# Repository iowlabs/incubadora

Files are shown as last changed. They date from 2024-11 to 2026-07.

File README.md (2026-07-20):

# incubadora

This project consists of a low-cost incubator for biotechnology instrumentation. Its design is easy to integrate and adaptable to different scenarios. It is ideal for remote laboratories, field deployments, school laboratories, and educational kits.

For this project, a PCB was designed that implements the electronics to control the operation of an incubator. It includes a temperature control and a *shaker* for sample agitation.

The PCB is based on a ESP32 so It can implement remote control and monitoring via Wi-Fi or BLE. It also has access to a USB communication interface for parameter configuration, curve generation, and data acquisition. It also features a simple interface that uses an LCD display and a rotary encoder as an alternative control method.

## Features.

### General features:

- Temperature Control
- Shaker RPM Control
- Simple User Interface
- WiFi Remote Control Capability
- Temperature profile programming
- easy assembly

### Hardware Features

- ESP32 Microcontroller
- PID Temperature Control Loop
	- Heater: Peltier-controlled by a H-bridge (2 separated heater channels)
	- Temperature Sensor: SHT31 ambient temperature and humidity sensor via I²C
	- Fan Assembly
- Shaker Control:
	- Nema 17 Motor
	- DRV8825 Polulu Controller
- Local User Interface
	- Rotary Encoder
	- LCD Display
	- SD Card
- WiFi Remote Control
	- MQTT Commands
- INA219 Current Sensor for Measuring Input Power Consumption

---
# Documentación

- Github repo
- Web

## Licencias

| | Licence |
|---- | --- |
|Hardware | --------- |
|Firmware and Software | --------- |
|Documentation and files | --------- |

---

# Diseño e implementación

---

## PCB
### Schematic

### pcb BOM

---

## Case 3D and structure

---

## List of components

### Assembly steps

---

## Firmware

### Used libraries

### Structure of the code

### Available Features.

---

# Application examples

## Using a portable cooler as incubator.

## Using a large incubator.

## Code to acquire and plot data in real time.

## Controlling via MQTT.

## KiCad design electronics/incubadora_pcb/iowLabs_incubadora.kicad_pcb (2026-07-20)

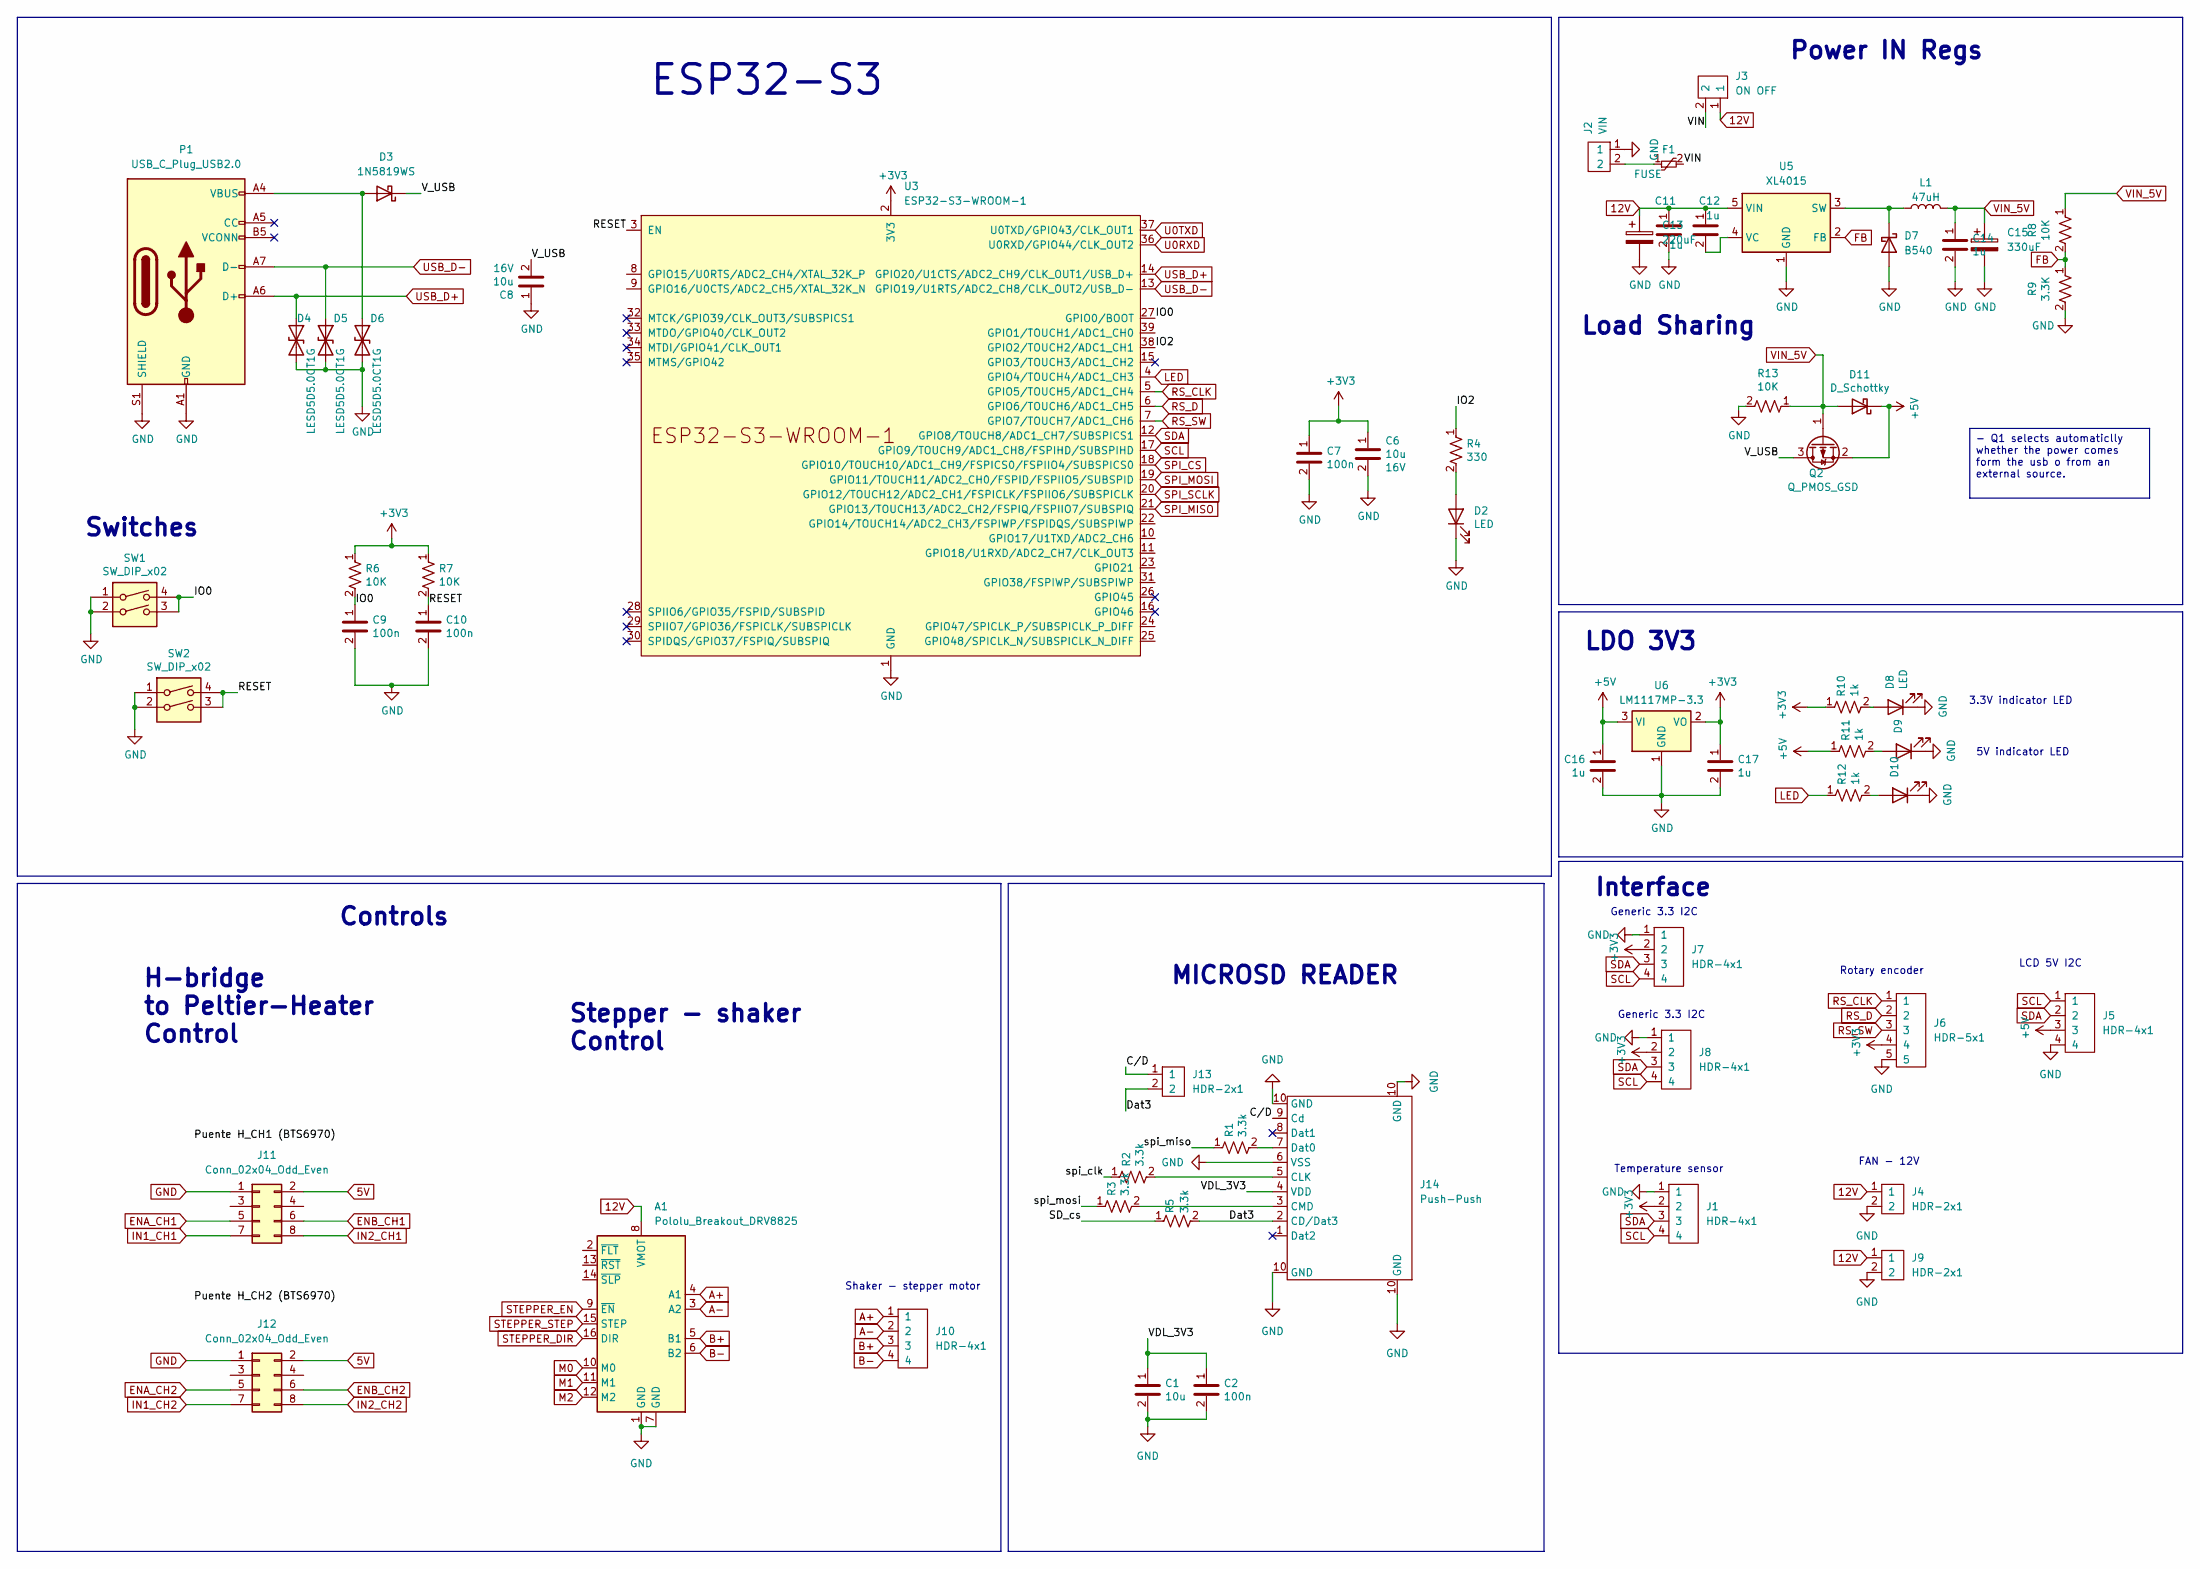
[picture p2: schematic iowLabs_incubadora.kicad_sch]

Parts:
A1: Pololu_Breakout_DRV8825; Pololu_Breakout-16_15.2x20.3mm
C1, C6, C8: 10u; C_0805_2012Metric; Voltage rated 16V
C2, C7, C9, C10: 100n; C_0603_1608Metric; Voltage rated 16V
C11, C12, C14, C16, C17: 1u; C_0805_2012Metric; Voltage rated 16V
C13: 220uF; CP_Elec_8x10.5; Voltage 50V
C15: 330uF; CP_Elec_8x10.5; Voltage 25V
D2, D8, D9, D10: LED; LED_0603_1608Metric
D3: 1N5819WS; D_SOD-323
D4, D5, D6: LESD5D5.0CT1G; D_SOD-523
D7: B540; D_SMB_Handsoldering
D11: D_Schottky; D_SMA
F1: FUSE; Fuse_1206_3216Metric
J1, J5, J7, J8, J10: HDR-4x1; JST_XH_B4B-XH-A_1x04_P2.50mm_Vertical
J2: VIN; Tb-2x1-5p-TH-V
J3: ON OFF; PinHeader_1x02_P2.54mm_Vertical
J4, J9: HDR-2x1
J6: HDR-5x1; JST_XH_B5B-XH-A_1x05_P2.50mm_Vertical
J11, J12: Conn_02x04_Odd_Even; PinHeader_2x04_P2.54mm_Vertical
J13: HDR-2x1; PinHeader_1x02_P2.54mm_Vertical
J14: microSD_push_push
L1: 47uH; L_12x12mm_H8mm
P1: USB_C_Plug_USB2.0; USB_C_Receptacle_GCT_USB4105-xx-A_16P_TopMnt_Horizontal
Q2: Q_PMOS_GSD; SOT-23
R1, R2, R3, R5: 3.3k; R_0603_1608Metric
R4: 330; R_0603_1608Metric
R6, R7, R8, R13: 10K; R_0603_1608Metric
R9: 3.3K; R_0603_1608Metric
R10, R11, R12: 1k; R_0603_1608Metric
SW1, SW2: SW_DIP_x02; SMD_SWITCH
U3: ESP32-S3-WROOM-1
U5: XL4015; TO-263-5_TabPin3
U6: LM1117MP-3.3; SOT-223-3_TabPin2

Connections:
5V: J11.2, J12.2
12V: A1.8 (VMOT), C11.1, C12.1, C13.1, J3.1, J4.1, J9.1, U5.5 (VIN)
+3V3: C6.1, C7.1, C17.1, J1.2, J6.4, J7.2, J8.2, R6.1, R7.1, R10.1, U3.2 (3V3), U6.2 (VO)
+5V: C16.1, D11.1 (K), J5.3, Q2.2 (S), R11.1, U6.3 (VI)
/C/D: J13.1, J14.9 (Cd)
/Dat3: J13.2, J14.2 (CD/Dat3), R5.2
/IO0: C9.1, R6.2, SW1.3, SW1.4, U3.27 (GPIO0/BOOT)
/IO2: R4.1, U3.38 (GPIO2/TOUCH2/ADC1_CH1)
/RESET: C10.1, R7.2, SW2.3, SW2.4, U3.3 (EN)
/SD_cs: R5.1
/VDL_3V3: C1.1, C2.1, J14.4 (VDD)
/VIN: F1.2, J3.2
/V_USB: C8.2, D3.1 (K), Q2.3 (D)
/spi_clk: R2.1
/spi_miso: R1.1
/spi_mosi: R3.1
A+: A1.4 (A1), J10.1
A-: A1.3 (A2), J10.2
B+: A1.5 (B1), J10.3
B-: A1.6 (B2), J10.4
ENA_CH1: J11.5
ENA_CH2: J12.5
ENB_CH1: J11.6
ENB_CH2: J12.6
FB: R8.2, R9.1, U5.2 (FB)
GND: A1.1 (GND), A1.7 (GND), C1.2, C2.2, C6.2, C7.2, C8.1, C9.2, C10.2, C11.2, C13.2, C14.2, C15.2, C16.2, C17.2, D2.1 (K), D4.2 (A2), D5.2 (A2), D6.2 (A2), D7.2 (A), D8.1 (K), D9.1 (K), D10.1 (K), J1.1, J2.1, J4.2, J5.4, J6.5, J7.1, J8.1, J9.2, J11.1, J12.1, J14.6 (VSS), J14.10 (GND), P1.A1 (GND), P1.A12 (GND), P1.B1 (GND), P1.B12 (GND), P1.S1 (SHIELD), R9.2, R13.2, SW1.1, SW1.2, SW2.1, SW2.2, U3.1 (GND), U3.40 (GND), U3.41 (GND), U5.1 (GND), U6.1 (GND)
IN1_CH1: J11.7
IN1_CH2: J12.7
IN2_CH1: J11.8
IN2_CH2: J12.8
LED: R12.1, U3.4 (GPIO4/TOUCH4/ADC1_CH3)
M0: A1.10 (M0)
M1: A1.11 (M1)
M2: A1.12 (M2)
unnamed: D2.2 (A), R4.2
unnamed: D3.2 (A), D6.1 (A1), P1.A4 (VBUS), P1.A9 (VBUS), P1.B4 (VBUS), P1.B9 (VBUS)
unnamed: D7.1 (K), L1.1, U5.3 (SW)
unnamed: D8.2 (A), R10.2
unnamed: D9.2 (A), R11.2
unnamed: D10.2 (A), R12.2
unnamed: F1.1, J2.2
unnamed: J14.5 (CLK), R2.2
unnamed: J14.3 (CMD), R3.2
unnamed: J14.7 (Dat0), R1.2
unnamed: C12.2, U5.4 (VC)
RS_CLK: J6.1, U3.5 (GPIO5/TOUCH5/ADC1_CH4)
RS_D: J6.2, U3.6 (GPIO6/TOUCH6/ADC1_CH5)
RS_SW: J6.3, U3.7 (GPIO7/TOUCH7/ADC1_CH6)
SCL: J1.4, J5.1, J7.4, J8.4, U3.17 (GPIO9/TOUCH9/ADC1_CH8/FSPIHD/SUBSPIHD)
SDA: J1.3, J5.2, J7.3, J8.3, U3.12 (GPIO8/TOUCH8/ADC1_CH7/SUBSPICS1)
SPI_CS: U3.18 (GPIO10/TOUCH10/ADC1_CH9/FSPICS0/FSPIIO4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)
SPI_MISO: U3.21 (GPIO13/TOUCH13/ADC2_CH2/FSPIQ/FSPIIO7/S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)
SPI_MOSI: U3.19 (GPIO11/TOUCH11/ADC2_CH0/FSPID/FSPIIO5/S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)
SPI_SCLK: U3.20 (GPIO12/TOUCH12/ADC2_CH1/FSPICLK/FSPIIO6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)
STEPPER_DIR: A1.16 (DIR)
STEPPER_EN: A1.9 (~EN)
STEPPER_STEP: A1.15 (STEP)
U0RXD: U3.36 (U0RXD/GPIO44/CLK_OUT2)
U0TXD: U3.37 (U0TXD/GPIO43/CLK_OUT1)
USB_D+: D4.1 (A1), P1.A6 (D+), U3.14 (GPIO20/U1CTS/ADC2_CH9/CLK_OUT1/USB_D+)
USB_D-: D5.1 (A1), P1.A7 (D-), U3.13 (GPIO19/U1RTS/ADC2_CH8/CLK_OUT2/USB_D-)
VIN_5V: C14.1, C15.1, D11.2 (A), L1.2, Q2.1 (G), R8.1, R13.1

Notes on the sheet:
LCD 5V I2C
3.3V indicator LED
H-bridge to Peltier-Heater Control
MICROSD READER
Power IN Regs
Load Sharing
5V indicator LED
Interface
FAN - 12V
Shaker - stepper motor
Controls
Generic 3.3 I2C
Stepper - shaker Control
Switches
ESP32-S3
Rotary encoder
LDO 3V3
Temperature sensor
- Q1 selects automaticlly whether the power comes form the usb o from an external source.

Board: 2 copper layers, 59 parts (0 on the bottom side), 38 nets, no tracks yet.

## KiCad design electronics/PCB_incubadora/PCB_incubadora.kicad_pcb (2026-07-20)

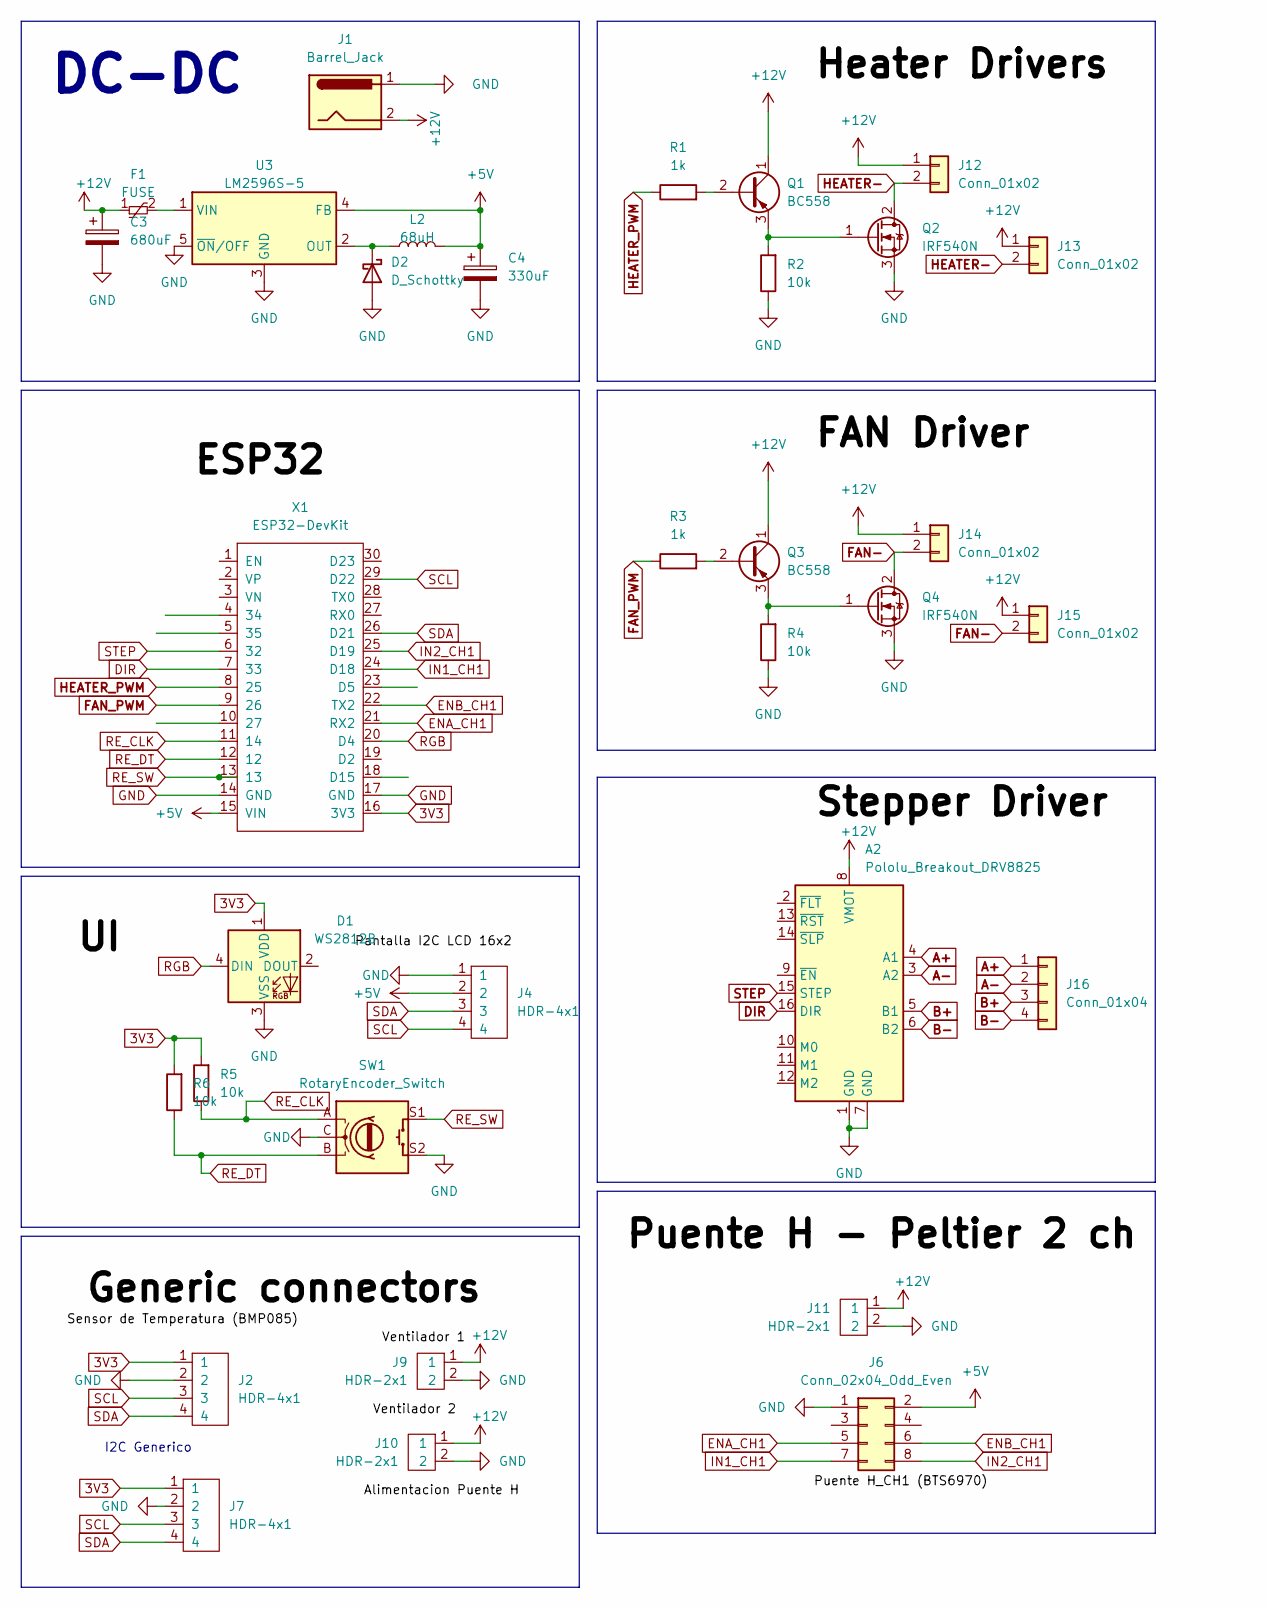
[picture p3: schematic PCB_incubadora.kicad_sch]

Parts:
A2: Pololu_Breakout_DRV8825; Pololu_Breakout-16_15.2x20.3mm
C3: 680uF; CP_Elec_10x10
C4: 330uF; CP_Elec_10x10
D1: WS2812B; LED_WS2812B_PLCC4_5.0x5.0mm_P3.2mm
D2: D_Schottky; D_SMB_Handsoldering
F1: FUSE; Fuse_1206_3216Metric
J1: Barrel_Jack; BarrelJack_Horizontal
J2, J7: HDR-4x1; JST_XH_B4B-XH-A_1x04_P2.50mm_Vertical
J4: HDR-4x1; OLED 0'96 SPI module
J6: Conn_02x04_Odd_Even; PinHeader_2x04_P2.54mm_Vertical
J9, J10, J11: HDR-2x1; TerminalBlock_4Ucon_1x02_P3.50mm_Horizontal
J12, J13, J14, J15: Conn_01x02; TerminalBlock_4Ucon_1x02_P3.50mm_Horizontal
J16: Conn_01x04; TerminalBlock_4Ucon_1x04_P3.50mm_Horizontal
L2: 68uH; L_12x12mm_H6mm
Q1, Q3: BC558; TO-92_Inline
Q2, Q4: IRF540N; TO-220-3_Vertical
R1, R3: 1k; R_0603_1608Metric
R2, R4, R5, R6: 10k; R_0603_1608Metric
SW1: RotaryEncoder_Switch; RotaryEncoder_Alps_EC11E-Switch_Vertical_H20mm
U3: LM2596S-5; TO-263-5_TabPin3
X1: ESP32-DevKit; ESP32_devkit

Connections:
3V3: D1.1 (VDD), J2.1, J7.1, R5.2, R6.2, X1.16 (3V3)
+5V: C4.1, J4.2, J6.2, L2.2, U3.4 (FB), X1.15 (VIN)
+12V: A2.8 (VMOT), C3.1, F1.1, J1.2, J9.1, J10.1, J11.1, J12.1, J13.1, J14.1, J15.1, Q1.1 (C), Q3.1 (C)
A+: A2.4 (A1), J16.1
A-: A2.3 (A2), J16.2
B+: A2.5 (B1), J16.3
B-: A2.6 (B2), J16.4
DIR: A2.16 (DIR), X1.7 (33)
ENA_CH1: J6.5, X1.21 (RX2)
ENB_CH1: J6.6, X1.22 (TX2)
FAN-: J14.2, J15.2, Q4.2 (D)
FAN_PWM: R3.1, X1.9 (26)
GND: A2.1 (GND), A2.7 (GND), C3.2, C4.2, D1.3 (VSS), D2.2 (A), J1.1, J2.2, J4.1, J6.1, J7.2, J9.2, J10.2, J11.2, Q2.3 (S), Q4.3 (S), R2.1, R4.1, SW1.C, SW1.S2, U3.3 (GND), U3.5 (~ON/OFF), X1.14 (GND), X1.17 (GND)
HEATER-: J12.2, J13.2, Q2.2 (D)
HEATER_PWM: R1.1, X1.8 (25)
IN1_CH1: J6.7, X1.24 (D18)
IN2_CH1: J6.8, X1.25 (D19)
unnamed: D2.1 (K), L2.1, U3.2 (OUT)
unnamed: Q1.2 (B), R1.2
unnamed: Q1.3 (E), Q2.1 (G), R2.2
unnamed: Q3.2 (B), R3.2
unnamed: Q3.3 (E), Q4.1 (G), R4.2
unnamed: F1.2, U3.1 (VIN)
RE_CLK: R5.1, SW1.A, X1.11 (14)
RE_DT: R6.1, SW1.B, X1.12
RE_SW: SW1.S1, X1.13
RGB: D1.4 (DIN), X1.20 (D4)
SCL: J2.3, J4.4, J7.3, X1.29 (D22)
SDA: J2.4, J4.3, J7.4, X1.26 (D21)
STEP: A2.15 (STEP), X1.6 (32)

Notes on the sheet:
I2C Generico
DC-DC

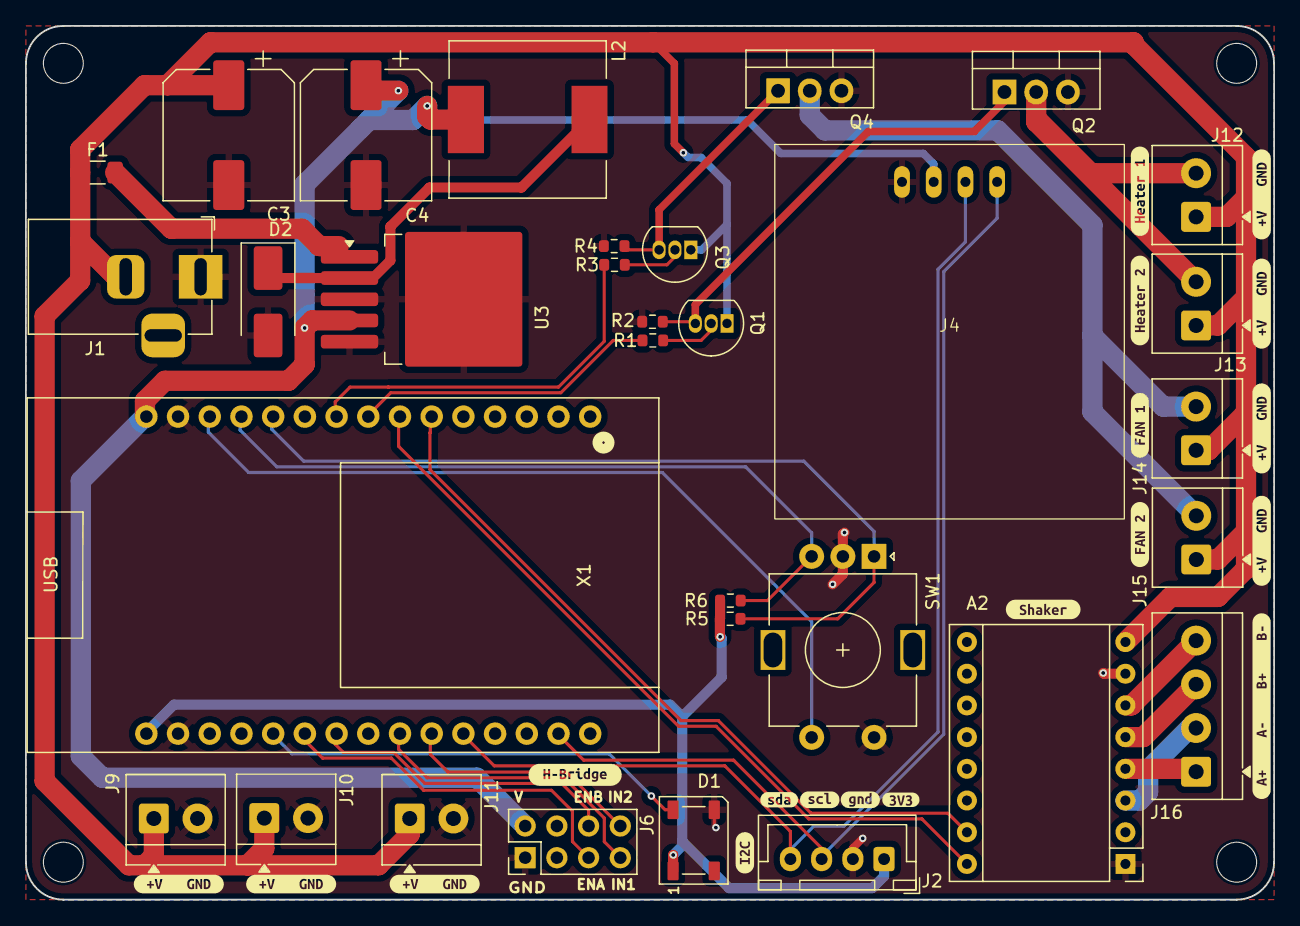
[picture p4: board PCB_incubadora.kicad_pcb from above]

Board: 2 copper layers, 100.0 x 70.0 mm, 51 parts (0 on the bottom side), 30 nets.

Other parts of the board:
kibuzzard-6A5B10A0: G***; kibuzzard-6A5B10A0
kibuzzard-6A5B10F5, kibuzzard-6A5B10F5#2, kibuzzard-6A5B10F5#3, kibuzzard-6A5B10F5#4, kibuzzard-6A5B10F5#5, kibuzzard-6A5B10F5#6, kibuzzard-6A5B10F5#7: G***; kibuzzard-6A5B10F5
kibuzzard-6A5B11C6: G***; kibuzzard-6A5B11C6
kibuzzard-6A5B13D0: G***; kibuzzard-6A5B13D0
kibuzzard-6A5B13E5: G***; kibuzzard-6A5B13E5
kibuzzard-6A5B13F6: G***; kibuzzard-6A5B13F6
kibuzzard-6A5B162D: G***; kibuzzard-6A5B162D
kibuzzard-6A5B1115: G***; kibuzzard-6A5B1115
kibuzzard-6A5B1189: G***; kibuzzard-6A5B1189
kibuzzard-6A5B1258: G***; kibuzzard-6A5B1258
kibuzzard-6A5B1282: G***; kibuzzard-6A5B1282
kibuzzard-6A5B1312: G***; kibuzzard-6A5B1312
kibuzzard-6A5B1426: G***; kibuzzard-6A5B1426

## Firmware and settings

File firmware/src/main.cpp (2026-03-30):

/*
# SPDX-FileCopyrightText: 2024 iowlabs <contacto@iowlabs.com>
#
# SPDX-License-Identifier: GPL-3.0-or-later.txt
*/

#include <Arduino.h>
#include <Wire.h>
#include <Adafruit_Sensor.h>
#include <Adafruit_SHT31.h>
#include <ArduinoJson.h>
#include <ContinuousStepper.h>
#include <LiquidCrystal_I2C.h>
#include <PID_v1.h>
#include <WiFi.h>
#include <AsyncTCP.h>
#include <ESPAsyncWebServer.h>
#include "freertos/FreeRTOS.h"
#include "freertos/task.h"
#include "freertos/semphr.h"

// Heater/H-bridge pins
#define ENA 25
#define ENB 26
#define IN1 33
#define IN2 32

// Stepper pins
#define PIN_DIR 27
#define PIN_STEP 14

// PWM channels
#define CH_H 5
#define CH_C 4

// Safe defaults and limits
constexpr float DEFAULT_TEMP_SP_C = 37.0f;
constexpr long DEFAULT_RPM = 60;
constexpr bool DEFAULT_RUN_ENABLED = false;

constexpr float TEMP_MIN_C = 15.0f;
constexpr float TEMP_MAX_C = 60.0f;
constexpr long RPM_MIN = 30;
constexpr long RPM_MAX = 90;

constexpr float STEPS_PER_REV = 1600.0f;
constexpr float RPM_TO_STEPS_PER_SEC = STEPS_PER_REV / 60.0f;

constexpr uint32_t CONTROL_INTERVAL_MS = 500;
constexpr uint32_t SSE_INTERVAL_MS = 500;

// Access point credentials (WPA2)
constexpr char AP_SSID[] = "Incubadora-ESP32";
constexpr char AP_PASSWORD[] = "incubadora32";

SemaphoreHandle_t stateMutex;

Adafruit_SHT31 sht31 = Adafruit_SHT31();
ContinuousStepper<StepperDriver> stepper;
LiquidCrystal_I2C lcd(0x27, 16, 2);

// PID setup
static double setpointPid = DEFAULT_TEMP_SP_C;
static double inputPid = 0.0;
static double outputPid = 0.0;
static double kp = 15.0;
static double ki = 2.0;
static double kd = 10.0;
PID temperaturePid(&inputPid, &outputPid, &setpointPid, kp, ki, kd, DIRECT);

// Web server + SSE
AsyncWebServer server(80);
AsyncEventSource events("/api/stream");

struct IncubatorState
{
  float temp_c;
  float temp_sp_c;
  long rpm;
  int pwm;
  bool run_enabled;
  uint32_t uptime_ms;
  char last_error[96];
};

IncubatorState gState;

const char INDEX_HTML[] PROGMEM = R"HTML(
<!doctype html>
<html lang="en">
<head>
  <meta charset="utf-8" />
  <meta name="viewport" content="width=device-width, initial-scale=1" />
  <title>Incubadora Control</title>
  <style>
    :root {
      --bg: radial-gradient(circle at 20% 20%, #14213d 0%, #0d1b2a 45%, #08121f 100%);
      --card: rgba(255, 255, 255, 0.08);
      --card-border: rgba(255, 255, 255, 0.18);
      --text: #f1f5f9;
      --muted: #cbd5e1;
      --ok: #34d399;
      --warn: #f59e0b;
      --bad: #f87171;
      --accent: #38bdf8;
      --accent-2: #22d3ee;
    }

    * { box-sizing: border-box; }

    body {
      margin: 0;
      min-height: 100vh;
      font-family: "Trebuchet MS", "Segoe UI", sans-serif;
      color: var(--text);
      background: var(--bg);
      display: grid;
      place-items: center;
      padding: 20px;
    }

    .panel {
      width: min(960px, 100%);
      border: 1px solid var(--card-border);
      background: var(--card);
      backdrop-filter: blur(8px);
      border-radius: 20px;
      padding: 20px;
      box-shadow: 0 24px 80px rgba(0, 0, 0, 0.35);
      animation: rise 450ms ease-out;
    }

    @keyframes rise {
      from { opacity: 0; transform: translateY(8px); }
      to { opacity: 1; transform: translateY(0); }
    }

    h1 {
      margin: 0 0 6px;
      font-size: clamp(1.2rem, 2.4vw, 1.8rem);
      letter-spacing: 0.04em;
      text-transform: uppercase;
    }

    .sub {
      margin: 0 0 18px;
      color: var(--muted);
      font-size: 0.95rem;
    }

    .grid {
      display: grid;
      gap: 12px;
      grid-template-columns: repeat(auto-fit, minmax(160px, 1fr));
      margin-bottom: 18px;
    }

    .card {
      background: rgba(2, 6, 23, 0.35);
      border: 1px solid rgba(148, 163, 184, 0.25);
      border-radius: 14px;
      padding: 12px;
    }

    .label {
      color: var(--muted);
      font-size: 0.78rem;
      text-transform: uppercase;
      letter-spacing: 0.08em;
    }

    .value {
      font-size: 1.4rem;
      margin-top: 4px;
      font-weight: 700;
    }

    .controls {
      display: grid;
      gap: 12px;
      grid-template-columns: repeat(auto-fit, minmax(220px, 1fr));
    }

    .input-group {
      display: grid;
      gap: 6px;
    }

    label {
      font-size: 0.85rem;
      color: var(--muted);
    }

    input {
      width: 100%;
      border-radius: 10px;
      border: 1px solid rgba(148, 163, 184, 0.4);
      background: rgba(2, 6, 23, 0.55);
      color: var(--text);
      font-size: 1rem;
      padding: 10px 12px;
      outline: none;
    }

    input:focus {
      border-color: var(--accent);
      box-shadow: 0 0 0 2px rgba(56, 189, 248, 0.25);
    }

    .actions {
      display: flex;
      gap: 8px;
      flex-wrap: wrap;
      margin-top: 2px;
    }

    button {
      border: none;
      border-radius: 10px;
      padding: 10px 14px;
      color: #042f2e;
      font-weight: 700;
      cursor: pointer;
      transition: transform 120ms ease, filter 120ms ease;
      background: linear-gradient(135deg, var(--accent), var(--accent-2));
    }

    button:hover { transform: translateY(-1px); filter: brightness(1.06); }

    .btn-stop {
      color: #450a0a;
      background: linear-gradient(135deg, #fca5a5, #f87171);
    }

    .btn-export {
      color: #082f49;
      background: linear-gradient(135deg, #93c5fd, #60a5fa);
    }

    .btn-clear {
      color: #3f2a00;
      background: linear-gradient(135deg, #fde68a, #fbbf24);
    }

    .status {
      margin-top: 14px;
      font-size: 0.88rem;
      color: var(--muted);
      min-height: 1.2rem;
    }

    .pill {
      display: inline-block;
      border-radius: 999px;
      padding: 3px 10px;
      font-size: 0.75rem;
      font-weight: 700;
      letter-spacing: 0.05em;
      margin-left: 6px;
    }

    .ok { background: rgba(52, 211, 153, 0.2); color: #86efac; }
    .warn { background: rgba(245, 158, 11, 0.2); color: #fcd34d; }
    .bad { background: rgba(248, 113, 113, 0.2); color: #fecaca; }

    .chart-card {
      margin-top: 14px;
    }

    .chart-wrap {
      margin-top: 10px;
      width: 100%;
      height: 230px;
      border-radius: 12px;
      border: 1px solid rgba(148, 163, 184, 0.3);
      background: rgba(2, 6, 23, 0.55);
      overflow: hidden;
    }

    #graphCanvas {
      width: 100%;
      height: 100%;
      display: block;
    }

    .chart-legend {
      margin-top: 10px;
      display: flex;
      gap: 16px;
      flex-wrap: wrap;
      color: var(--muted);
      font-size: 0.82rem;
    }

    .chart-key {
      display: inline-flex;
      align-items: center;
      gap: 7px;
    }

    .chart-dot {
      width: 10px;
      height: 10px;
      border-radius: 999px;
      display: inline-block;
    }

    .dot-temp { background: #22d3ee; }
    .dot-pwm { background: #f59e0b; }
  </style>
</head>
<body>
  <main class="panel">
    <h1>Incubadora + Shaker</h1>
    <p class="sub">
      AP control interface
      <span id="connPill" class="pill warn">CONNECTING</span>
    </p>

    <section class="grid">
      <article class="card"><div class="label">Temperature (C)</div><div id="tempVal" class="value">--</div></article>
      <article class="card"><div class="label">Setpoint (C)</div><div id="spVal" class="value">--</div></article>
      <article class="card"><div class="label">PWM</div><div id="pwmVal" class="value">--</div></article>
      <article class="card"><div class="label">RPM</div><div id="rpmVal" class="value">--</div></article>
      <article class="card"><div class="label">Run State</div><div id="runVal" class="value">--</div></article>
      <article class="card"><div class="label">Uptime (s)</div><div id="upVal" class="value">--</div></article>
    </section>

    <section class="controls">
      <div class="input-group">
        <label for="tempInput">Temperature Setpoint (15.0 to 60.0 C)</label>
        <input id="tempInput" type="number" min="15" max="60" step="0.1" value="37.0" />
      </div>
      <div class="input-group">
        <label for="rpmInput">Shaker RPM (30 to 90)</label>
        <input id="rpmInput" type="number" min="30" max="90" step="1" value="60" />
      </div>
    </section>

    <div class="actions">
      <button id="applyBtn">Apply</button>
      <button id="startBtn">Start</button>
      <button id="stopBtn" class="btn-stop">Stop</button>
      <button id="clearBtn" class="btn-clear">Clear History</button>
      <button id="downloadBtn" class="btn-export">Download CSV</button>
    </div>

    <div id="statusMsg" class="status"></div>

    <section class="card chart-card">
      <div class="label">Live Temperature and PWM</div>
      <div class="chart-wrap">
        <canvas id="graphCanvas"></canvas>
      </div>
      <div class="chart-legend">
        <span class="chart-key"><i class="chart-dot dot-temp"></i>Temperature (C)</span>
        <span class="chart-key"><i class="chart-dot dot-pwm"></i>PWM (0-255)</span>
      </div>
    </section>
  </main>

  <script>
    const TEMP_MIN = 15.0;
    const TEMP_MAX = 60.0;
    const RPM_MIN = 30;
    const RPM_MAX = 90;
    const PWM_MIN = 0;
    const PWM_MAX = 255;
    const CSV_MAX_ROWS = 5000;
    const HISTORY_STORAGE_KEY = 'incubadora_history_v1';
    const HISTORY_SAVE_DEBOUNCE_MS = 300;
    const UPTIME_RESET_TOLERANCE_MS = 2000;

    const els = {
      tempVal: document.getElementById('tempVal'),
      spVal: document.getElementById('spVal'),
      pwmVal: document.getElementById('pwmVal'),
      rpmVal: document.getElementById('rpmVal'),
      runVal: document.getElementById('runVal'),
      upVal: document.getElementById('upVal'),
      tempInput: document.getElementById('tempInput'),
      rpmInput: document.getElementById('rpmInput'),
      applyBtn: document.getElementById('applyBtn'),
      startBtn: document.getElementById('startBtn'),
      stopBtn: document.getElementById('stopBtn'),
      clearBtn: document.getElementById('clearBtn'),
      downloadBtn: document.getElementById('downloadBtn'),
      statusMsg: document.getElementById('statusMsg'),
      connPill: document.getElementById('connPill'),
      graphCanvas: document.getElementById('graphCanvas')
    };

    const graphHistory = {
      timeS: [],
      temp: [],
      pwm: []
    };
    const csvHistory = [];
    let lastGraphUptime = -1;
    let historySaveTimer = null;

    function setConnState(kind, label) {
      els.connPill.className = 'pill ' + kind;
      els.connPill.textContent = label;
    }

    function setStatus(text, isError = false) {
      els.statusMsg.textContent = text || '';
      els.statusMsg.style.color = isError ? '#fecaca' : '#cbd5e1';
    }

    function fmt1(v) {
      return Number.isFinite(v) ? v.toFixed(1) : '--';
    }

    function clamp(v, min, max) {
      return Math.max(min, Math.min(max, v));
    }

    function addGraphPoint(uptimeMs, temp, pwm) {
      if (!Number.isFinite(uptimeMs) || !Number.isFinite(temp) || !Number.isFinite(pwm)) {
        return;
      }

      graphHistory.timeS.push(uptimeMs / 1000);
      graphHistory.temp.push(temp);
      graphHistory.pwm.push(pwm);

      drawGraph();
      scheduleHistorySave();
    }

    function formatElapsed(seconds) {
      const s = Math.max(0, Math.round(seconds));
      const h = Math.floor(s / 3600);
      const m = Math.floor((s % 3600) / 60);
      const sec = s % 60;
      if (h > 0) {
        return h + 'h ' + String(m).padStart(2, '0') + 'm';
      }
      if (m > 0) {
        return m + 'm ' + String(sec).padStart(2, '0') + 's';
      }
      return sec + 's';
    }

    function addCsvRow(sample) {
      csvHistory.push(sample);
      if (csvHistory.length > CSV_MAX_ROWS) {
        csvHistory.shift();
      }
      scheduleHistorySave();
    }

    function saveHistoryNow() {
      const history = {
        v: 1,
        lastGraphUptime,
        graphHistory,
        csvHistory
      };
      try {
        localStorage.setItem(HISTORY_STORAGE_KEY, JSON.stringify(history));
      } catch (_) {
        // Ignore storage quota/private-mode failures.
      }
    }

    function scheduleHistorySave() {
      if (historySaveTimer !== null) {
        return;
      }
      historySaveTimer = setTimeout(() => {
        historySaveTimer = null;
        saveHistoryNow();
      }, HISTORY_SAVE_DEBOUNCE_MS);
    }

    function clearHistory(persist = true) {
      graphHistory.timeS.length = 0;
      graphHistory.temp.length = 0;
      graphHistory.pwm.length = 0;
      csvHistory.length = 0;
      lastGraphUptime = -1;
      drawGraph();
      if (persist) {
        saveHistoryNow();
      }
    }

    function restoreHistory() {
      let raw = '';
      try {
        raw = localStorage.getItem(HISTORY_STORAGE_KEY) || '';
      } catch (_) {
        return;
      }
      if (!raw) {
        return;
      }

      try {
        const parsed = JSON.parse(raw);
        if (!parsed || typeof parsed !== 'object') {
          return;
        }

        const g = parsed.graphHistory;
        const c = parsed.csvHistory;
        if (!g || !Array.isArray(g.timeS) || !Array.isArray(g.temp) || !Array.isArray(g.pwm) || !Array.isArray(c)) {
          return;
        }

        const n = Math.min(g.timeS.length, g.temp.length, g.pwm.length);
        for (let i = 0; i < n; i += 1) {
          const t = Number(g.timeS[i]);
          const temp = Number(g.temp[i]);
          const pwm = Number(g.pwm[i]);
          if (!Number.isFinite(t) || !Number.isFinite(temp) || !Number.isFinite(pwm)) {
            continue;
          }
          graphHistory.timeS.push(t);
          graphHistory.temp.push(temp);
          graphHistory.pwm.push(pwm);
        }

        const rowsToCopy = c.slice(-CSV_MAX_ROWS);
        for (const row of rowsToCopy) {
          if (!row || typeof row !== 'object') {
            continue;
          }
          csvHistory.push(row);
        }

        const persistedUptime = Number(parsed.lastGraphUptime);
        if (Number.isFinite(persistedUptime)) {
          lastGraphUptime = persistedUptime;
        } else if (graphHistory.timeS.length > 0) {
          lastGraphUptime = Math.round(graphHistory.timeS[graphHistory.timeS.length - 1] * 1000);
        }
      } catch (_) {
        // Corrupt storage should not break UI.
      }
    }

    function csvEscape(value) {
      const text = String(value ?? '');
      if (text.includes(',') || text.includes('"') || text.includes('\n')) {
        return '"' + text.replaceAll('"', '""') + '"';
      }
      return text;
    }

    function buildCsv() {
      const header = [
        'captured_at_iso',
        'uptime_ms',
        'temperature_c',
        'pwm',
        'rpm',
        'temp_sp_c',
        'run_enabled'
      ];
      const lines = [header.join(',')];

      for (const row of csvHistory) {
        lines.push([
          csvEscape(row.captured_at_iso),
          csvEscape(row.uptime_ms),
          csvEscape(row.temperature_c),
          csvEscape(row.pwm),
          csvEscape(row.rpm),
          csvEscape(row.temp_sp_c),
          csvEscape(row.run_enabled)
        ].join(','));
      }

      return lines.join('\n');
    }

    function downloadCsv() {
      if (csvHistory.length === 0) {
        setStatus('No live samples yet. Wait for telemetry before exporting.', true);
        return;
      }

      const csvText = buildCsv();
      const stamp = new Date().toISOString().replace(/[:]/g, '-').replace(/\..+/, '');
      const fileName = 'incubadora_temp_pwm_' + stamp + '.csv';
      const blob = new Blob([csvText], { type: 'text/csv;charset=utf-8;' });
      const url = URL.createObjectURL(blob);

      const link = document.createElement('a');
      link.href = url;
      link.download = fileName;
      document.body.appendChild(link);
      link.click();
      link.remove();
      URL.revokeObjectURL(url);

      setStatus('CSV downloaded (' + csvHistory.length + ' samples).');
    }

    function drawGraph() {
      const canvas = els.graphCanvas;
      if (!canvas) {
        return;
      }

      const ctx = canvas.getContext('2d');
      if (!ctx) {
        return;
      }

      const width = canvas.clientWidth || 300;
      const height = canvas.clientHeight || 220;
      const dpr = window.devicePixelRatio || 1;
      const targetW = Math.max(1, Math.floor(width * dpr));
      const targetH = Math.max(1, Math.floor(height * dpr));

      if (canvas.width !== targetW || canvas.height !== targetH) {
        canvas.width = targetW;
        canvas.height = targetH;
      }

      ctx.setTransform(dpr, 0, 0, dpr, 0, 0);
      ctx.clearRect(0, 0, width, height);

      const padLeft = 38;
      const padRight = 38;
      const padTop = 12;
      const padBottom = 30;
      const plotLeft = padLeft;
      const plotTop = padTop;
      const plotWidth = Math.max(10, width - padLeft - padRight);
      const plotHeight = Math.max(10, height - padTop - padBottom);
      const plotBottom = plotTop + plotHeight;
      const plotRight = plotLeft + plotWidth;

      ctx.fillStyle = 'rgba(2, 6, 23, 0.65)';
      ctx.fillRect(plotLeft, plotTop, plotWidth, plotHeight);

      ctx.strokeStyle = 'rgba(148, 163, 184, 0.22)';
      ctx.lineWidth = 1;
      for (let i = 0; i <= 4; i += 1) {
        const y = plotTop + (plotHeight * i) / 4;
        ctx.beginPath();
        ctx.moveTo(plotLeft, y);
        ctx.lineTo(plotRight, y);
        ctx.stroke();
      }

      ctx.fillStyle = 'rgba(203, 213, 225, 0.9)';
      ctx.font = '11px Trebuchet MS';
      ctx.textAlign = 'left';
      ctx.fillText(TEMP_MAX.toFixed(0) + 'C', 4, plotTop + 4);
      ctx.fillText(TEMP_MIN.toFixed(0) + 'C', 4, plotBottom + 4);
      ctx.textAlign = 'right';
      ctx.fillText(String(PWM_MAX), width - 4, plotTop + 4);
      ctx.fillText(String(PWM_MIN), width - 4, plotBottom + 4);
      ctx.textAlign = 'left';

      const points = graphHistory.temp.length;
      if (points < 1) {
        return;
      }

      const startTimeS = graphHistory.timeS[0];
      const endTimeS = graphHistory.timeS[points - 1];
      const spanS = Math.max(1, endTimeS - startTimeS);

      ctx.strokeStyle = 'rgba(148, 163, 184, 0.20)';
      ctx.lineWidth = 1;
      ctx.textAlign = 'center';
      for (let i = 0; i <= 4; i += 1) {
        const x = plotLeft + (plotWidth * i) / 4;
        ctx.beginPath();
        ctx.moveTo(x, plotTop);
        ctx.lineTo(x, plotBottom);
        ctx.stroke();

        const tickElapsed = (spanS * i) / 4;
        ctx.fillStyle = 'rgba(203, 213, 225, 0.9)';
        ctx.fillText(formatElapsed(tickElapsed), x, height - 6);
      }
      ctx.textAlign = 'left';

      const xForTime = (timeS) => plotLeft + (plotWidth * (timeS - startTimeS)) / spanS;
      const yTemp = (val) => {
        const norm = (clamp(val, TEMP_MIN, TEMP_MAX) - TEMP_MIN) / (TEMP_MAX - TEMP_MIN);
        return plotBottom - (norm * plotHeight);
      };
      const yPwm = (val) => {
        const norm = (clamp(val, PWM_MIN, PWM_MAX) - PWM_MIN) / (PWM_MAX - PWM_MIN);
        return plotBottom - (norm * plotHeight);
      };

      ctx.strokeStyle = '#22d3ee';
      ctx.lineWidth = 2;
      ctx.beginPath();
      ctx.moveTo(xForTime(graphHistory.timeS[0]), yTemp(graphHistory.temp[0]));
      for (let i = 1; i < points; i += 1) {
        ctx.lineTo(xForTime(graphHistory.timeS[i]), yTemp(graphHistory.temp[i]));
      }
      ctx.stroke();

      ctx.strokeStyle = '#f59e0b';
      ctx.lineWidth = 2;
      ctx.beginPath();
      ctx.moveTo(xForTime(graphHistory.timeS[0]), yPwm(graphHistory.pwm[0]));
      for (let i = 1; i < points; i += 1) {
        ctx.lineTo(xForTime(graphHistory.timeS[i]), yPwm(graphHistory.pwm[i]));
      }
      ctx.stroke();
    }

    function renderState(s) {
      const tempNum = Number(s.temp_c);
      const setpointNum = Number(s.temp_sp_c);
      const pwmNum = Number(s.pwm);
      const rpmNum = Number(s.rpm);
      const uptimeNum = Number(s.uptime_ms);

      els.tempVal.textContent = fmt1(tempNum);
      els.spVal.textContent = fmt1(Number(s.temp_sp_c));
      els.pwmVal.textContent = Number.isFinite(pwmNum) ? pwmNum : '--';
      els.rpmVal.textContent = Number.isFinite(rpmNum) ? rpmNum : '--';
      els.runVal.textContent = s.run_enabled ? 'RUNNING' : 'STOPPED';
      els.upVal.textContent = Number.isFinite(uptimeNum) ? Math.floor(uptimeNum / 1000) : '--';
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
void loop()
{
  static uint32_t lastControlMs = 0;
  static uint32_t lastSseMs = 0;

  // Keep all stepper operations in a single task context.
  stepper.loop();

  uint32_t now = millis();

  if (Serial.available() > 0)
  {
    processSerialCommand();
  }

  if ((now - lastControlMs) >= CONTROL_INTERVAL_MS)
  {
    lastControlMs = now;

    IncubatorState state = snapshotState();
    float measuredTemp = sht31.readTemperature();
    bool tempValid = !isnan(measuredTemp);
    int pwmToApply = 0;

    if (tempValid)
    {
      setpointPid = state.temp_sp_c;
      inputPid = static_cast<double>(measuredTemp);
      temperaturePid.Compute();
      pwmToApply = constrain(static_cast<int>(lround(outputPid)), 0, 255);
    }
    else
    {
      setLastError("Temperature read failed");
      measuredTemp = state.temp_c;
    }

    if (!state.run_enabled)
    {
      pwmToApply = 0;
    }

    updateStateTelemetry(measuredTemp, pwmToApply, now);
    state = snapshotState();
    applyActuators(state, tempValid, pwmToApply);
    updateLcd(state);

    String serialTelemetry = buildLegacySerialTelemetry();
    Serial.println(serialTelemetry);
  }

  if ((now - lastSseMs) >= SSE_INTERVAL_MS)
  {
    lastSseMs = now;
    String payload = buildStateJson();
    events.send(payload.c_str(), "state", now);
  }
}

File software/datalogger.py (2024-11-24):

import serial
import json
import matplotlib.pyplot as plt
import matplotlib.animation as animation
from collections import deque
import threading
import time
import datetime
import csv

# Configuración del puerto serial
SERIAL_PORT = '/dev/ttyUSB0'  # Cambia esto al puerto adecuado (e.g., '/dev/ttyUSB0' en Linux)
BAUD_RATE = 115200
TIMEOUT = 1
PATH 	= '/data/'


# Tamaño máximo de los buffers
MAX_LEN = 1000  # Ajusta según tus necesidades

# Buffers circulares para almacenar los datos
tiempo_buffer = deque(maxlen=MAX_LEN)
temp_buffer = deque(maxlen=MAX_LEN)
pwm_buffer = deque(maxlen=MAX_LEN)
sp_buffer =  deque(maxlen=MAX_LEN)

# Variable para controlar el hilo de lectura
running = True
file_name = ""


def saveData(_d1,_d2,_d3,_d4,_d5):
	with open(file_name, mode = 'a', newline='') as csv_file:
		writer_csv = csv.writer(csv_file)
		writer_csv.writerow([_d1,_d2,_d3,_d4,_d5])

def serial_reader():
	global running
	try:
		ser = serial.Serial(SERIAL_PORT, BAUD_RATE, timeout=TIMEOUT)
		print(f"Conectado al puerto serial: {SERIAL_PORT}")
	except serial.SerialException as e:
		print(f"Error al abrir el puerto serial: {e}")
		return

	while running:
		try:
			if ser.in_waiting > 0:
				line = ser.readline().decode('utf-8').strip()
				if line:
					try:
						data = json.loads(line)
						print(data)
						t = data['time']
						temp = data['temp']
						temp_sp = data['temp_sp']
						pwm = data['pwm']
						rpm = data['rpm']

						tiempo_buffer.append(t)
						temp_buffer.append(temp)
						pwm_buffer.append(pwm)
						sp_buffer.append(temp_sp)
						saveData(t,temp,temp_sp,pwm,rpm)
					except (json.JSONDecodeError, KeyError) as e:
						print(f"Error al procesar la línea: {line} | Error: {e}")
		except serial.SerialException as e:
			print(f"Error en la comunicación serial: {e}")
			break
		except UnicodeDecodeError as e:
			print(f"Error de decodificación: {e}")
		time.sleep(0.01)  # Pequeña pausa para evitar uso excesivo de CPU

	ser.close()
	print("Hilo de lectura serial terminado.")

# Iniciar el hilo de lectura serial
file_name = datetime.datetime.now().strftime("%Y-%m-%d_%H-%M")+".csv"
thread = threading.Thread(target=serial_reader, daemon=True)
thread.start()

# Configuración de la gráfica
fig, ax = plt.subplots()
line1, = ax.plot([], [], label="temp", color='tab:blue')
line2, = ax.plot([], [], label="pwm", color='tab:green')
line3, = ax.plot([], [], label="sp", color='tab:red')

ax.set_xlabel('Tiempo')
ax.set_ylabel('Temp')
ax.legend()
ax.grid(True)

# Inicialización de la gráfica
def init():
	ax.set_xlim(0, 10)  # Ventana inicial de tiempo
	ax.set_ylim(0, 10)  # Ajusta según tus datos
	line1.set_data([], [])
	line2.set_data([], [])
	line3.set_data([], [])

	return line1, line2, line3

# Actualización de la gráfica
def update(frame):
	if tiempo_buffer:
		# Obtener los datos actuales
		tiempos = list(tiempo_buffer)
		temperaturas = list(temp_buffer)
		pwms = list(pwm_buffer)
		sps = list(sp_buffer)
		#print(len(voltajes))

		# Actualizar las líneas de la gráfica
		line1.set_data(tiempos, temperaturas)
		line2.set_data(tiempos, pwms)
		line3.set_data(tiempos, sps)
		# Ajustar los límites de la gráfica
		ax.set_xlim(tiempos[0], tiempos[-1] + 1)
		y_min = min(min(temperaturas, default=0), min(pwms, default=0)) - 1
		y_max = max(max(temperaturas, default=10), max(sps, default=10)) + 1
		#y_max = max(temperaturas, default=10) + 1
		ax.set_ylim(y_min, y_max)
		ax.set_title("Temp ctrol incubadora")


	return line1, line2

# Configuración de la animación
ani = animation.FuncAnimation(fig, update, init_func=init, blit=False, interval=100)

# Función para cerrar el programa limpiamente
def on_close(event):
    global running
    print("Cerrando la aplicación...")
    running = False
    thread.join()

# Conectar el evento de cierre de la figura
fig.canvas.mpl_connect('close_event', on_close)

# Mostrar la gráfica
plt.show()

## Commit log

2024-11-23 testing heater control
2025-06-25 adding sch
    [PCB_incubadora.kicad_pcb, PCB_incubadora.kicad_sch, iowLabs_incubadora.kicad_pcb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]
2025-07-21 changing temp sensor
2025-07-23 shanging sensor
2026-03-30 Major firmware/web control update: API UI, motor fixes, and test setup
    [Proyecto_incubadora.cpp, calefactor_pid.cpp, calefactor_test.cpp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]
2026-07-20 updating 3d model of pcb
    [PCB_incubadora.kicad_pcb, PCB_incubadora.kicad_sch, iowLabs_incubadora.kicad_pcb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]
2026-09-28 updating pcb
2026-10-16 actualizando el readme
